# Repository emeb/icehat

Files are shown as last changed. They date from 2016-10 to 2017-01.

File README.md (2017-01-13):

# icehat

icehat is a small (Zero-sized) RPi hat which comprises a Lattice iCE40 Ultra
FPGA type ice5LP4K-SG48 along with voltage regulators, status LEDs and three
Digilent-style PMOD connectors.

This repository includes the full KiCAD board design source as well as C source
for an RPi user application which can configure the FPGA via GPIO and SPI ports
as well as communicate with a simple SPI slave hosted on the FPGA. Verilog
source for the FPGA test design is also included.

For more info on this project, please see the web page at:

http://ebrombaugh.studionebula.com/embedded/icehat/index.html

Credits: 

Portions of the KiCAD design are based on the RPi_Hat_Template from
xesscorp: https://github.com/xesscorp/RPi_Hat_Template

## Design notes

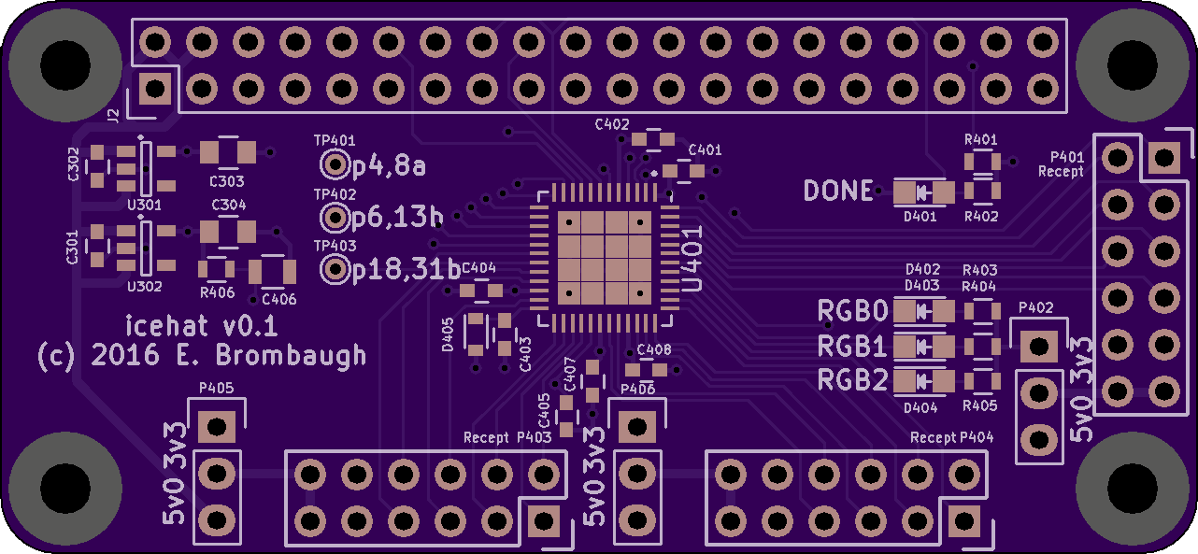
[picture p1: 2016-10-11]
docs/icehat_front.png

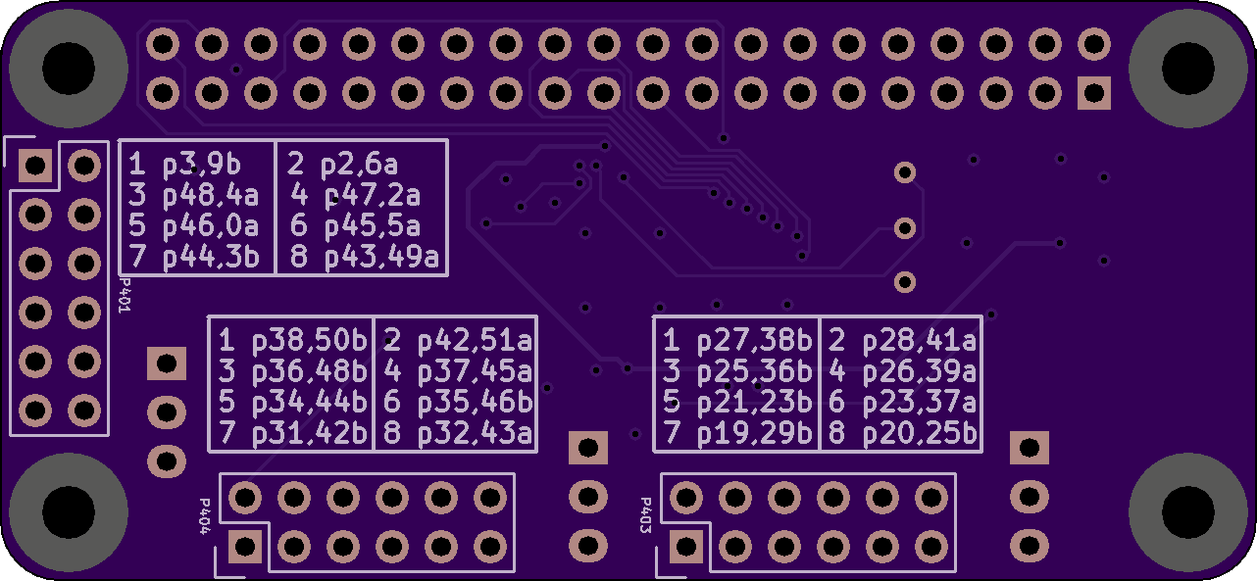
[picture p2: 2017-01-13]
docs/icehat_back.png

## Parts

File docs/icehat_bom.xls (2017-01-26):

Reference | Value | Footprint | M | Qty | Mfg P/N | Distributor | Distributor P/N | Notes
C401 | 0.1uf | Capacitors_SMD:C_0603 | 1
C402 | 0.1uf | Capacitors_SMD:C_0603 | 1
C403 | 0.1uf | Capacitors_SMD:C_0603 | 1
C404 | 0.1uf | Capacitors_SMD:C_0603 | 1
C405 | 0.1uf | Capacitors_SMD:C_0603 | 1
C407 | 0.1uf | Capacitors_SMD:C_0603 | 1
C408 | 0.1uf | Capacitors_SMD:C_0603 | 1 | 7 | C1608X7R1E104K080AA | Digi-Key | 445-1316-1-ND
C303 | 10uf | Capacitors_SMD:C_0805 | 1
C304 | 10uf | Capacitors_SMD:C_0805 | 1
C406 | 10uf | Capacitors_SMD:C_0805 | 1 | 3 | EMK212BB7106MG-T | Mouser | 963-EMK212BB7106MG-T
C301 | 1uf | Capacitors_SMD:C_0603 | 1
C302 | 1uf | Capacitors_SMD:C_0603 | 1 | 2 | GCM188R71E105KA64D | Mouser | 81-GCM188R71E105KA4D
D401 | LED | LEDs:LED_0805 | 1
D402 | LED | LEDs:LED_0805 | 1
D403 | LED | LEDs:LED_0805 | 1
D404 | LED | LEDs:LED_0805 | 1 | 4 | Generic 0805 LED
D405 | D | Diodes_SMD:D_0603 | 1 | 1 | CDSU4148 | Mouser | 750-CDSU4148
J2 | RPi_GPIO | emeb:Pin_Header_Straight_2x20 | 1 | 1 | M20-7832046 | Mouser | 855-M20-7832046
P402 | CONN_01X03 | Pin_Headers:Pin_Header_Straight_1x03 | 1
P405 | CONN_01X03 | Pin_Headers:Pin_Header_Straight_1x03 | 1
P406 | CONN_01X03 | Pin_Headers:Pin_Header_Straight_1x03 | 1 | 3 | Generic 0.1” pin headers
P401 | CONN_02X06 | Pin_Headers:Pin_Header_Straight_2x06 | 1
P403 | CONN_02X06 | Pin_Headers:Pin_Header_Straight_2x06 | 1
P404 | CONN_02X06 | Pin_Headers:Pin_Header_Straight_2x06 | 1 | 3 | PPPC062LJBN-RC | Digi-Key | S5559-ND
R401 | 10k | Resistors_SMD:R_0603 | 1
R406 | 100 | Resistors_SMD:R_0603 | 1 | 1 | ERJ-3GEYJ103V | Digi-Key | P10KGCT-ND
R402 | 2.2k | Resistors_SMD:R_0603 | 1 | 1 | ERJ-3GEYJ101V | Digi-Key | P100GCT-ND
R403 | 2.2k | Resistors_SMD:R_0603 | 1
R404 | 2.2k | Resistors_SMD:R_0603 | 1
R405 | 2.2k | Resistors_SMD:R_0603 | 1 | 4 | ERJ-3GEYJ222V | Digi-Key | P10KGCT-ND
U301 | MCP1802-3.3 | TO_SOT_Packages_SMD:SOT-23-5 | 1 | 1 | MCP1802T-3302I/OT | Digi-Key | MCP1802T-3302I/OTCT-ND
U302 | MCP1824-1.2 | TO_SOT_Packages_SMD:SOT-23-5 | 1 | 1 | MCP1824T-1202E/OT | Mouser | 579-MCP1824T-1202EOT
U401 | ice5lp4k_sg48 | emeb:QFN-48-1EP_7x7mm_Pitch0.5mm_DIY_PADS | 1 | 1 | ICE5LP4K-SG48ITR50 | Mouser | 842-CE5LP4KSG48ITR50

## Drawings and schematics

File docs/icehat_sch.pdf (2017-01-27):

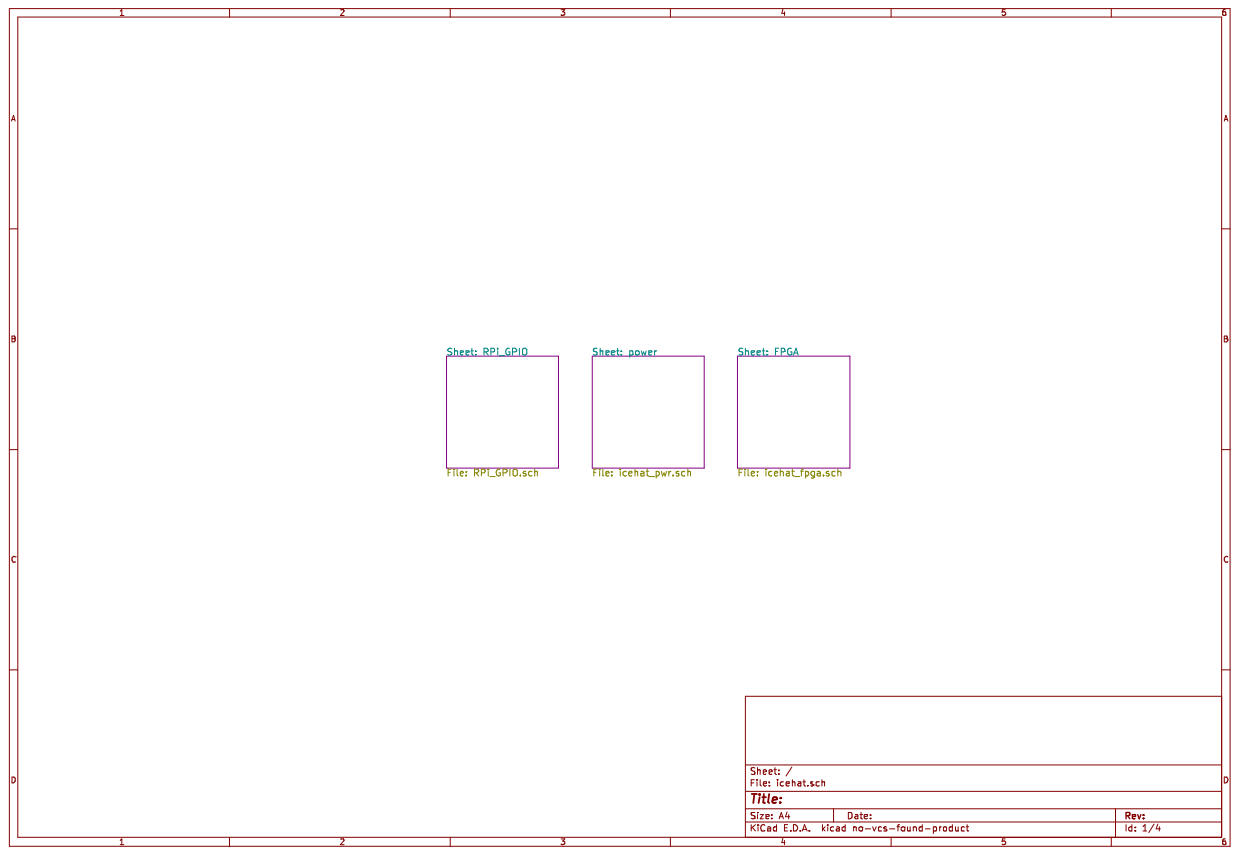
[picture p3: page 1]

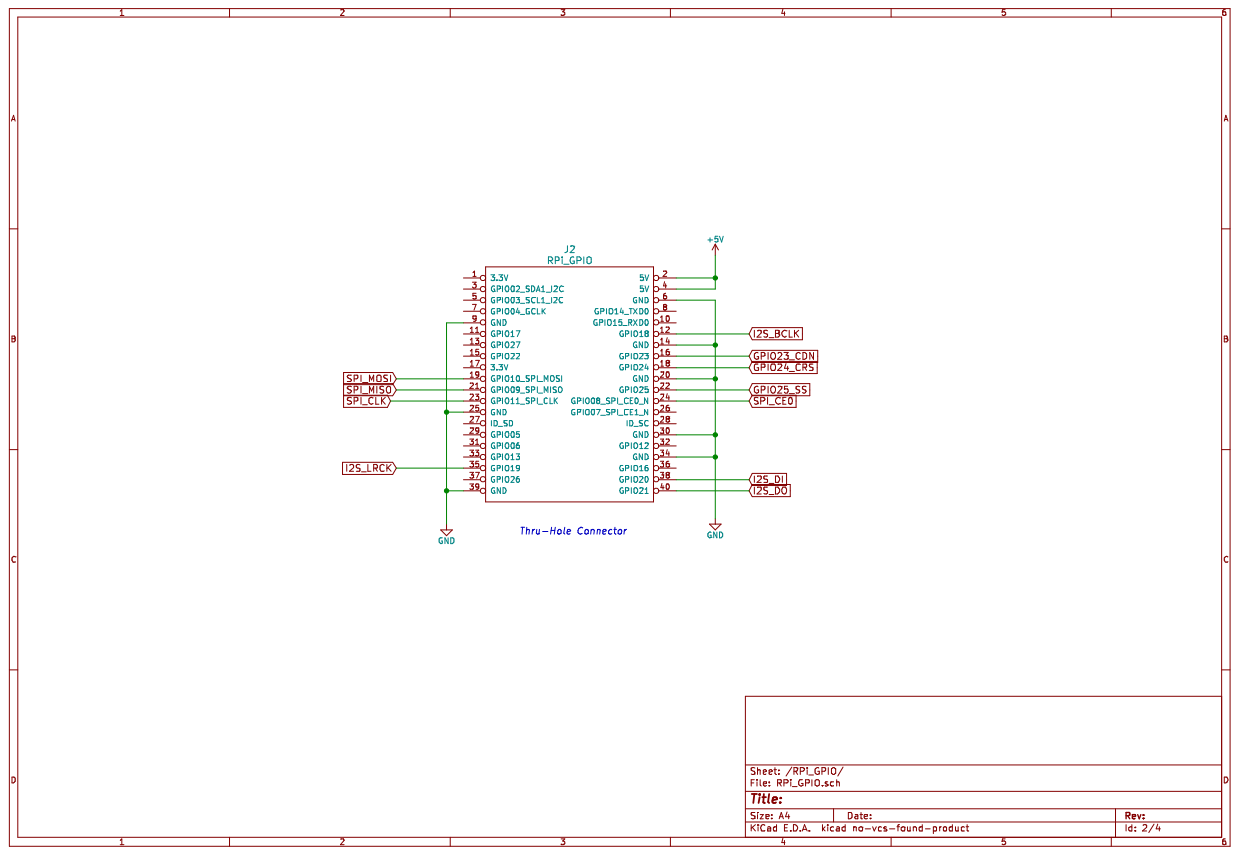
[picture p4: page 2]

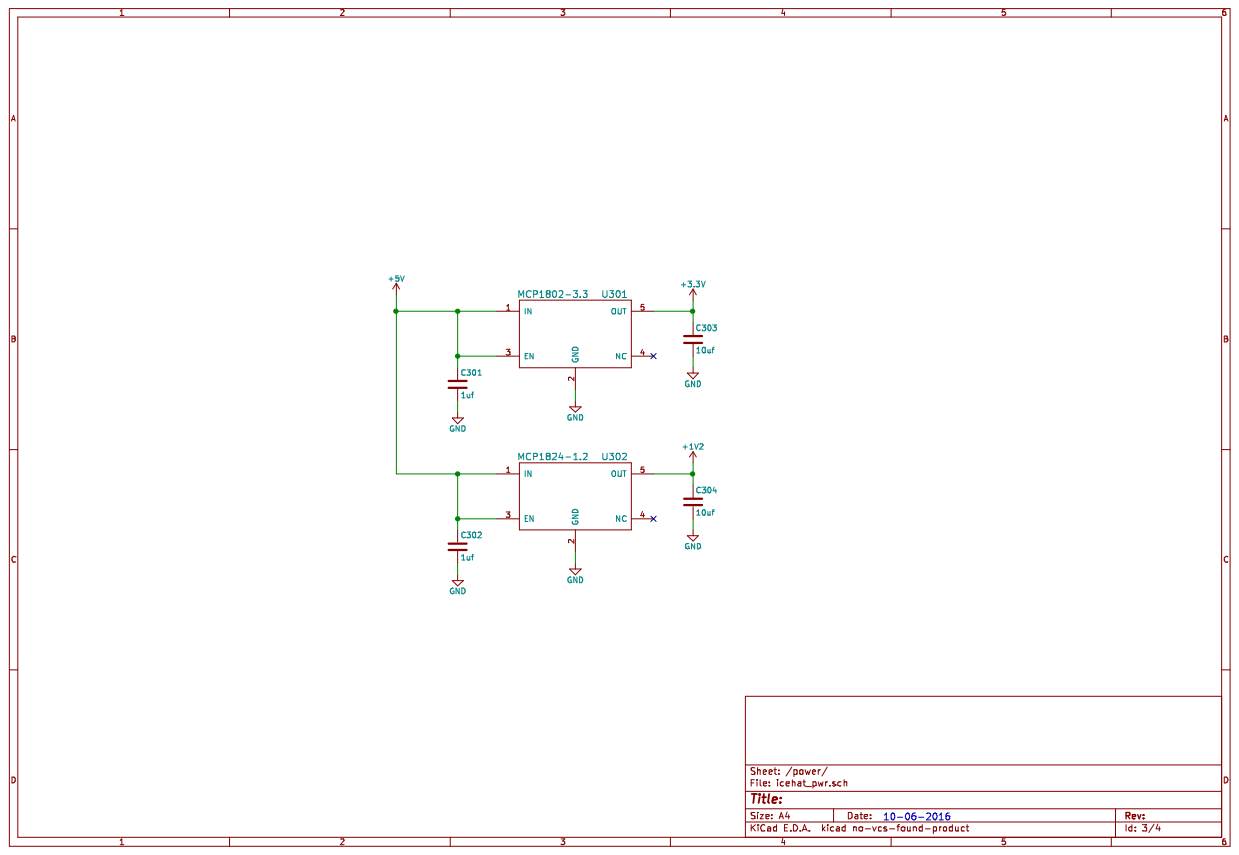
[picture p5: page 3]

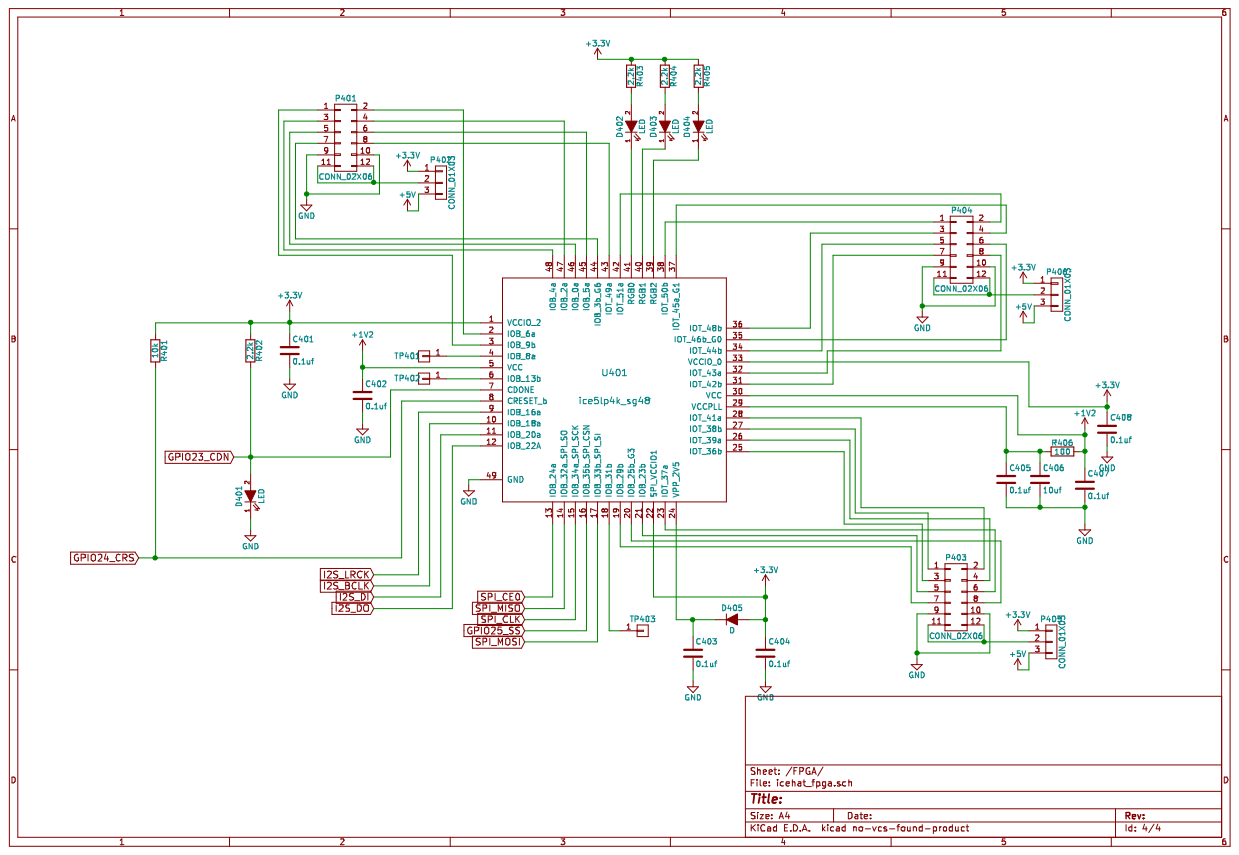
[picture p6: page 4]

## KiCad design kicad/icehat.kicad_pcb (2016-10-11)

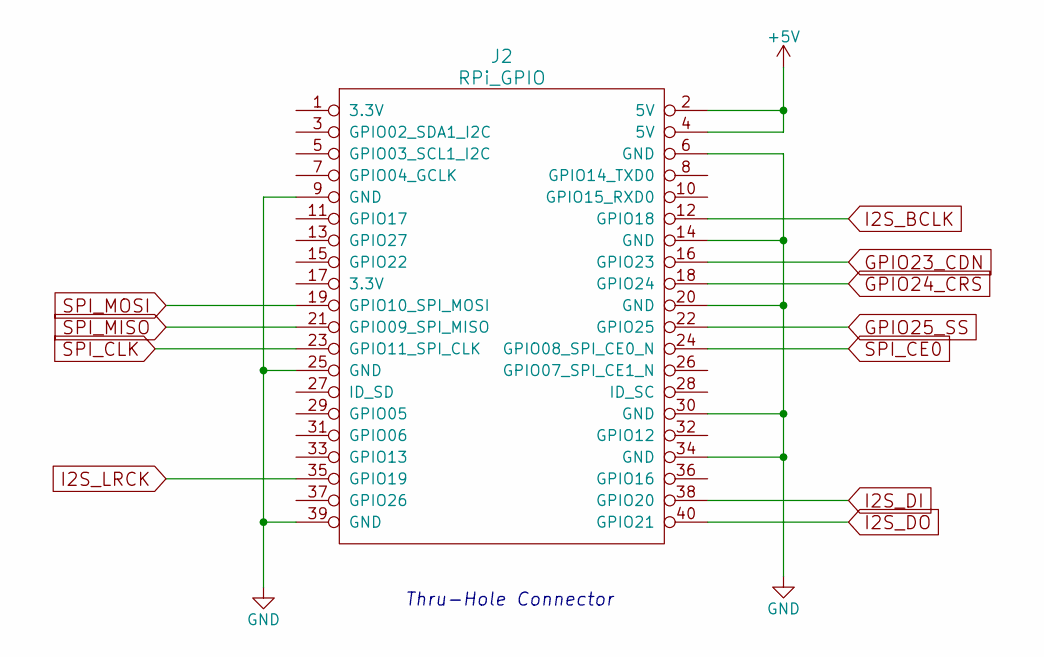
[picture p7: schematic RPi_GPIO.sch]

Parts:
J2: RPi_GPIO; Pin_Header_Straight_2x20

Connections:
+5V: J2.2 (5V), J2.4 (5V); also elsewhere on the board
GND: J2.6 (GND), J2.9 (GND), J2.14 (GND), J2.20 (GND), J2.25 (GND), J2.30 (GND), J2.34 (GND), J2.39 (GND); also elsewhere on the board
GPIO23_CDN: J2.16 (GPIO23); also elsewhere on the board
GPIO24_CRS: J2.18 (GPIO24); also elsewhere on the board
GPIO25_SS: J2.22 (GPIO25); also elsewhere on the board
I2S_BCLK: J2.12 (GPIO18); also elsewhere on the board
I2S_DI: J2.38 (GPIO20); also elsewhere on the board
I2S_DO: J2.40 (GPIO21); also elsewhere on the board
I2S_LRCK: J2.35 (GPIO19); also elsewhere on the board
SPI_CE0: J2.24 (GPIO08_SPI_CE0_N); also elsewhere on the board
SPI_CLK: J2.23 (GPIO11_SPI_CLK); also elsewhere on the board
SPI_MISO: J2.21 (GPIO09_SPI_MISO); also elsewhere on the board
SPI_MOSI: J2.19 (GPIO10_SPI_MOSI); also elsewhere on the board

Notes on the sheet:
Thru-Hole Connector

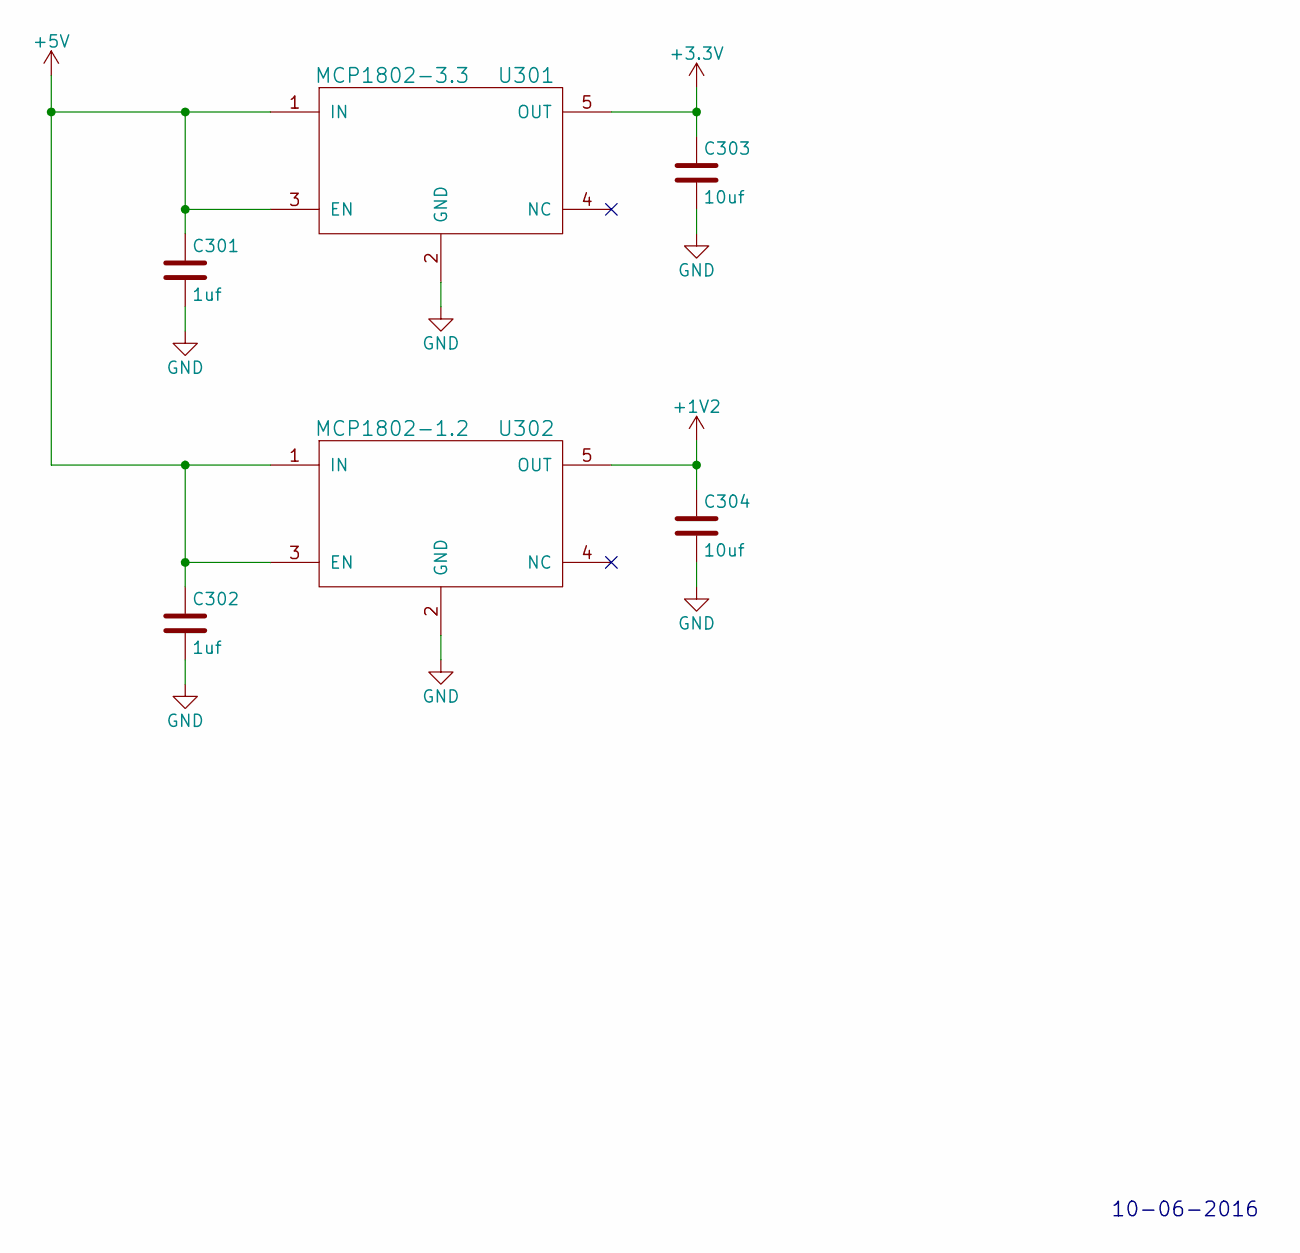
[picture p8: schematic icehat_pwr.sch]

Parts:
C301, C302: 1uf; C_0603
C303, C304: 10uf; C_0805
U301: MCP1802-3.3; SOT-23-5
U302: MCP1802-1.2; SOT-23-5

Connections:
+1V2: C304.1, U302.5 (OUT); also elsewhere on the board
+3V3: C303.1, U301.5 (OUT); also elsewhere on the board
+5V: C301.1, C302.1, U301.1 (IN), U301.3 (EN), U302.1 (IN), U302.3 (EN); also elsewhere on the board
GND: C301.2, C302.2, C303.2, C304.2, U301.2 (GND), U302.2 (GND); also elsewhere on the board

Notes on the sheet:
10-06-2016

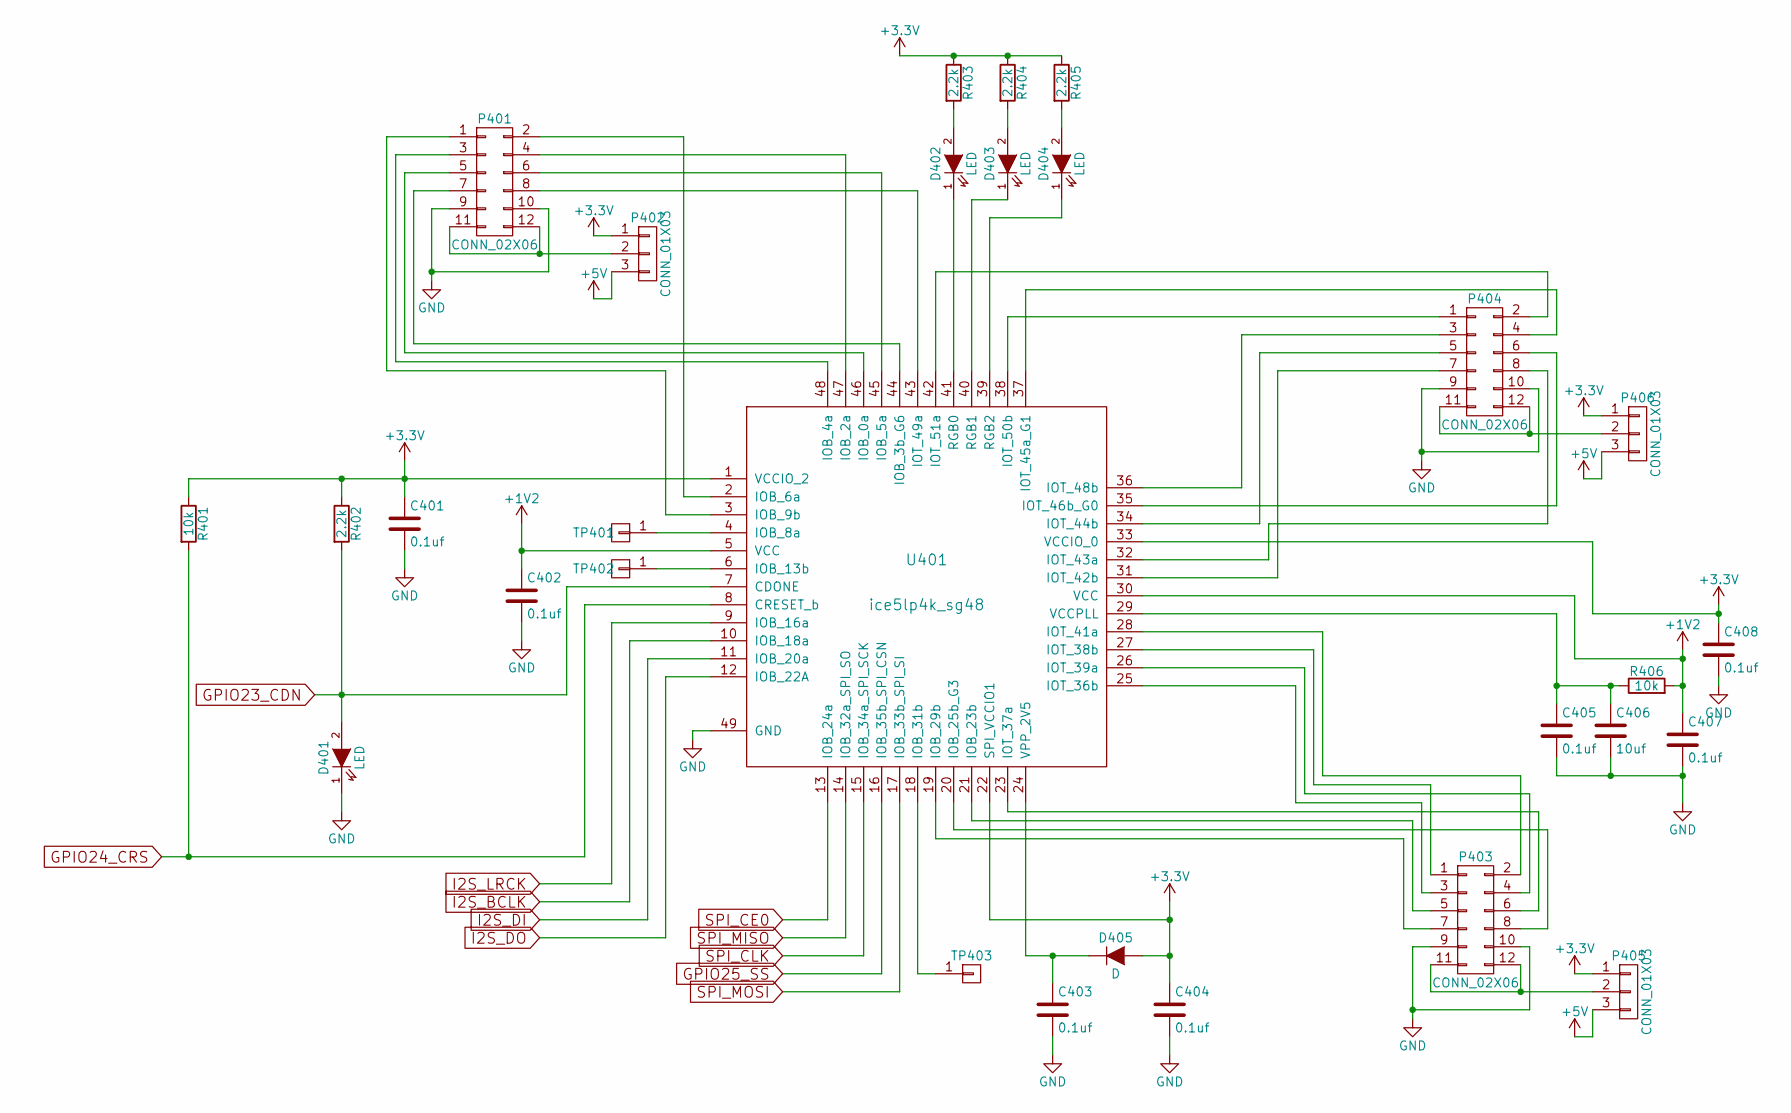
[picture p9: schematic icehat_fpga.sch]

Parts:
C401, C402, C403, C404, C405, C407, C408: 0.1uf; C_0603
C406: 10uf; R_0805
D401, D402, D403, D404: LED; LED_0805
D405: D; D_0603
P401, P403, P404: CONN_02X06; Pin_Header_Straight_2x06
P402, P405, P406: CONN_01X03; Pin_Header_Straight_1x03
R401, R406: 10k; R_0603
R402, R403, R404, R405: 2.2k; R_0603
TP401, TP402, TP403: CONN_01X01; PINTST
U401: ice5lp4k_sg48; QFN-48-1EP_7x7mm_Pitch0.5mm_DIY_PADS

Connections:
+1V2: C402.1, C407.1, R406.2, U401.5 (VCC), U401.30 (VCC); also elsewhere on the board
+3V3: C401.1, C404.1, C408.1, D405.2 (A), P402.1, P405.1, P406.1, R401.1, R402.1, R403.1, R404.1, R405.1, U401.1 (VCCIO_2), U401.22 (SPI_VCCIO1), U401.33 (VCCIO_0); also elsewhere on the board
+5V: P402.3, P405.3, P406.3; also elsewhere on the board
GND: C401.2, C402.2, C403.2, C404.2, C405.2, C406.2, C407.2, C408.2, D401.1 (K), P401.9, P401.10, P403.9, P403.10, P404.9, P404.10, U401.49 (GND); also elsewhere on the board
GPIO23_CDN: D401.2 (A), R402.2, U401.7 (CDONE); also elsewhere on the board
GPIO24_CRS: R401.2, U401.8 (CRESET_b); also elsewhere on the board
GPIO25_SS: U401.16 (IOB_35b_SPI_CSN); also elsewhere on the board
I2S_BCLK: U401.10 (IOB_18a); also elsewhere on the board
I2S_DI: U401.11 (IOB_20a); also elsewhere on the board
I2S_DO: U401.12 (IOB_22A); also elsewhere on the board
I2S_LRCK: U401.9 (IOB_16a); also elsewhere on the board
unnamed: C403.1, D405.1 (K), U401.24 (VPP_2V5)
unnamed: C405.1, C406.1, R406.1, U401.29 (VCCPLL)
unnamed: D402.1 (K), U401.41 (RGB0)
unnamed: D402.2 (A), R403.2
unnamed: D403.1 (K), U401.40 (RGB1)
unnamed: D403.2 (A), R404.2
unnamed: D404.1 (K), U401.39 (RGB2)
unnamed: D404.2 (A), R405.2
unnamed: P401.1, U401.3 (IOB_9b)
unnamed: P401.2, U401.2 (IOB_6a)
unnamed: P401.3, U401.48 (IOB_4a)
unnamed: P401.4, U401.47 (IOB_2a)
unnamed: P401.5, U401.46 (IOB_0a)
unnamed: P401.6, U401.45 (IOB_5a)
unnamed: P401.7, U401.44 (IOB_3b_G6)
unnamed: P401.8, U401.43 (IOT_49a)
unnamed: P401.11, P401.12, P402.2
unnamed: P403.1, U401.27 (IOT_38b)
unnamed: P403.2, U401.28 (IOT_41a)
unnamed: P403.3, U401.25 (IOT_36b)
unnamed: P403.4, U401.26 (IOT_39a)
unnamed: P403.5, U401.21 (IOB_23b)
unnamed: P403.6, U401.23 (IOT_37a)
unnamed: P403.7, U401.19 (IOB_29b)
unnamed: P403.8, U401.20 (IOB_25b_G3)
unnamed: P403.11, P403.12, P405.2
unnamed: P404.1, U401.38 (IOT_50b)
unnamed: P404.2, U401.42 (IOT_51a)
unnamed: P404.3, U401.36 (IOT_48b)
unnamed: P404.4, U401.37 (IOT_45a_G1)
unnamed: P404.5, U401.34 (IOT_44b)
unnamed: P404.6, U401.35 (IOT_46b_G0)
unnamed: P404.7, U401.31 (IOT_42b)
unnamed: P404.8, U401.32 (IOT_43a)
unnamed: P404.11, P404.12, P406.2
unnamed: TP401.1, U401.4 (IOB_8a)
unnamed: TP402.1, U401.6 (IOB_13b)
unnamed: TP403.1, U401.18 (IOB_31b)
SPI_CE0: U401.13 (IOB_24a); also elsewhere on the board
SPI_CLK: U401.15 (IOB_34a_SPI_SCK); also elsewhere on the board
SPI_MISO: U401.14 (IOB_32a_SPI_SO); also elsewhere on the board
SPI_MOSI: U401.17 (IOB_33b_SPI_SI); also elsewhere on the board

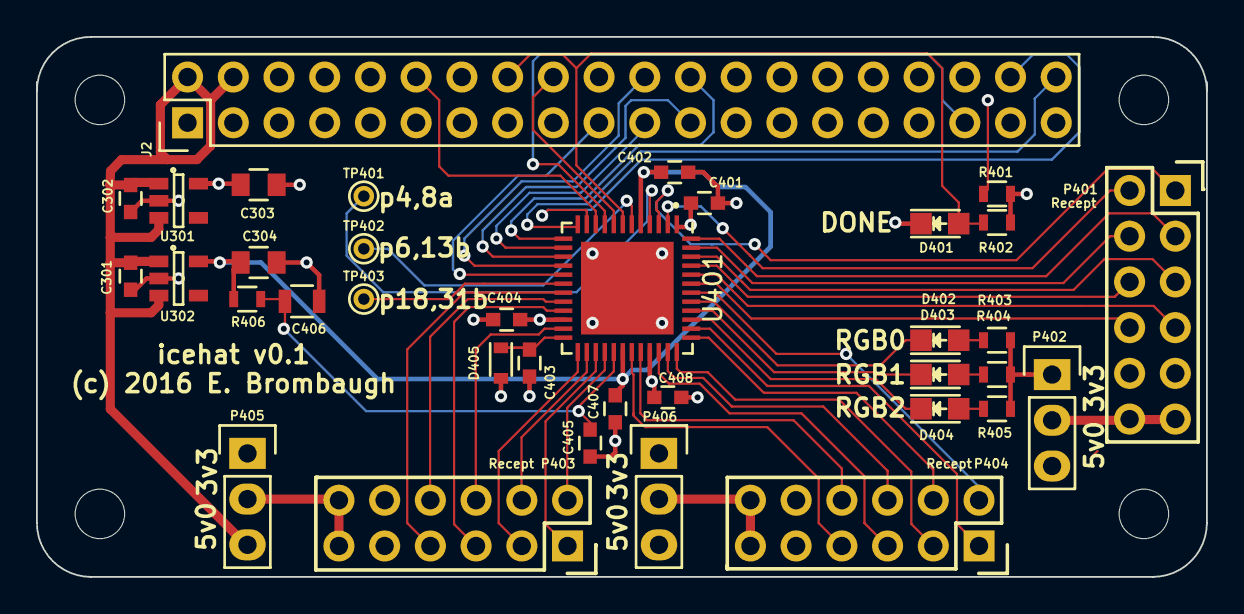
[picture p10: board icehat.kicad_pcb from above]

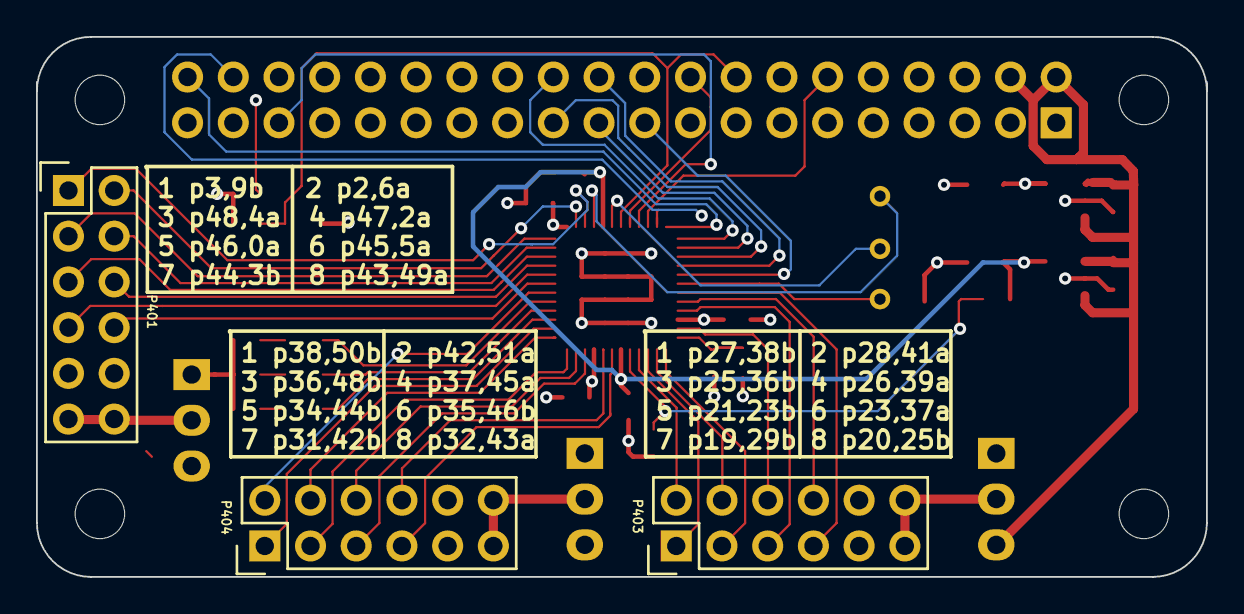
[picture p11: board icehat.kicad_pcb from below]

Board: 4 copper layers, 65.0 x 30.0 mm, 36 parts (3 on the bottom side), 53 nets.

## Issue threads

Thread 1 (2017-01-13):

How to program icehat?

liubenyuan, 2017-01-13:
Hi, Thanks for your project icehat.

I find that you do not have any jtag headers (sorry I just moved from Xilinx), how could I program icehat?

Or, can I add one FTDI pins to icehat?

emeb, 2017-01-13:
Lattice FPGAs do not require (or support) JTAG programming - they can
only be programmed via the SPI interface. On the Icehat the SPI
interface is connected to the Raspberry Pi SPI port so the FPGA can be
configured via programs running on the Raspberry Pi. In the github
repository I have provided source code for an application that can do
this, as well as a library of code that can be added to other applications.

Eric

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

liubenyuan, 2017-01-13:
Thanks ! Does ice40lp4k support LVDS input/output ? In
```
Using Differential I/O (LVDS, Sub-LVDS)
in iCE40 LP/HX Devices
```
It says that ice40lp4k has 20 lvds pairs, where are they ? I do not find any pins named as `_P` or `_N` as for Xilinx. I do not know whether this chip support long rang LVDS transmission.

emeb, 2017-01-13:
Lattice FPGAs do not require (or support) JTAG programming - they can only be programmed via the SPI interface. On the Icehat the SPI interface is connected to the Raspberry Pi SPI port so the FPGA can be configured via programs running on the Raspberry Pi. In the github repository I have provided source code for an application that can do this, as well as a library of code that can be added to other applications.

emeb, 2017-01-13:
Icehat does not use an LP/HX device - it is an Ultra device. Please see the data sheet for this family here:

http://www.latticesemi.com/view_document?document_id=51968

According to that document, LVDS is not specifically supported. It mentions that some pins provide differential input but then does not list which pins.

liubenyuan, 2017-01-13:
Thanks!

Closed 2017-01-13.

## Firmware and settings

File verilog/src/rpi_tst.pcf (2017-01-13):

# ##############################################################################

# iCEcube PCF

# Version:            2016.02.27810

# File Generated:     May 3 2016 09:34:27

# Family & Device:    iCE5LP4K

# Package:            SG48

# ##############################################################################

###IOSet List 17
set_io SPI_MISO 14
set_io SPI_SCLK 15
set_io SPI_CSL 13
set_io SPI_MOSI 17

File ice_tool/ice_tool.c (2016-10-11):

/* ice_tool.c - iCE40 configuration & control for raspberry pi               */
/* Copyright 2016 Eric Brombaugh                                             */
/*   This program is free software; you can redistribute it and/or modify
    it under the terms of the GNU General Public License as published by
    the Free Software Foundation; either version 2 of the License, or
    (at your option) any later version.

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
    You should have received a copy of the GNU General Public License
    along with this program; if not, write to the Free Software
    Foundation, Inc., 51 Franklin Street, Fifth Floor, Boston,
    MA 02110-1301 USA.
*/

#include <stdio.h>
#include <stdlib.h>
#include "ice_lib.h"

#define VERSION "0.1"
#define ARRAY_SIZE(a) (sizeof(a) / sizeof((a)[0]))

static void help(void) __attribute__ ((noreturn));

static void help(void)
{
	fprintf(stderr,
	    "Usage: ice_tool [-r addr][-w addr data][-v][-V] [BITSTREAM] \n"
		"  BITSTREAM is a file containing the FPGA bitstream to download\n"
		"  -r read SPI control port at addr\n"
		"  -w write SPI control port at addr w/ data\n"
		"  -v enables verbose progress messages\n"
		"  -V prints the tool version\n");
	exit(1);
}

int main(int argc, char **argv)
{
	iceblk *bs;
	int flags = 0, read = 0, write = 0, verbose = 0, cfg = 0;
	int addr = 0, data = 0;

	/* handle (optional) flags first */
	while (1+flags < argc && argv[1+flags][0] == '-')
	{
		switch (argv[1+flags][1])
		{
		case 'r':
			read = 1;
			if (2+flags < argc)
				addr = atoi(argv[flags+2]);
			flags++;
			break;
		case 'w':
			write = 1;
			if (2+flags < argc)
				addr = atoi(argv[flags+2]);
			if (3+flags < argc)
				data = atoi(argv[flags+3]);
			flags+=2;
			break;
		case 'v':
			verbose = 1;
			break;
		case 'V':
			fprintf(stderr, "ice_tool version %s\n", VERSION);
			exit(0);
		default:
			fprintf(stderr, "Error: Unsupported option "
				"\"%s\"!\n", argv[1+flags]);
			help();
			exit(1);
		}
		flags++;
	}
    
    /* configuring? */
	if(argc > flags + 1)
        cfg = 1;

	/* open up hardware */
	if((bs = ice_init(cfg, verbose)) == NULL)
	{
		fprintf(stderr, "Couldn't access hardware\n");
		exit(2);
	}
	
	/* send bitstream to FPGA or SPI Flash if bitfile name available*/
	if(cfg)
	{
        /* Configure FPGA */
        if(verbose == 1) fprintf(stderr, "Configuring FPGA...\n");

        if(ice_cfg(bs, argv[flags + 1]))
        {
            fprintf(stderr, "Error sending bitstream to FPGA\n");
        }
	}

	/* spi read/write? */
	if(read || write)
	{
		int ret;
		uint8_t tx[] = {0x00, 0x00, 0x00, 0x00, 0x00};
		uint8_t rx[ARRAY_SIZE(tx)] = {0, };
		
		/* Build message */
		tx[0] = addr & 0x7f;	// set address
		if(read)
		{
			fprintf(stderr, "Read 0x%02X\n", addr);
			tx[0] |= 0x80;
		}

		if(write)
		{
			fprintf(stderr, "Write 0x%02X 0x%08X\n", addr, data);
			tx[1] = (data >> 24) & 0xff;
			tx[2] = (data >> 16) & 0xff;
			tx[3] = (data >>  8) & 0xff;
			tx[4] = (data >>  0) & 0xff;
		}
 
		/* send a message */
		ret = ice_spi_txrx(bs, tx, rx, ARRAY_SIZE(tx));
		if (ret == 1)
		{
			fprintf(stderr, "Can't send spi message\n");
		}
		else
		{
			/* Dump RX Message */
			fprintf(stderr, "Sent: ");
			for (ret = 0; ret < ARRAY_SIZE(tx); ret++)
			{
				fprintf(stderr, "%.2X ", tx[ret]);
			}
			fprintf(stderr, "\n");
			fprintf(stderr, "Received: ");
			for (ret = 0; ret < ARRAY_SIZE(rx); ret++)
			{
				fprintf(stderr, "%.2X ", rx[ret]);
			}
			fprintf(stderr, "\n");
		}
	}
	
	/* All done */
	ice_delete(bs);
	
	return 0;
}

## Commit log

2016-10-11 Initial commit of icehat RPi FPGA hat.
    [RPi_GPIO.sch, icehat.kicad_pcb, icehat.sch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]
2016-10-11 Added board render and schematic
2017-01-26 Added BOM
    [icehat_bom.xls]
2017-01-27 Fix some component values
    [icehat_fpga.sch, icehat_pwr.sch]

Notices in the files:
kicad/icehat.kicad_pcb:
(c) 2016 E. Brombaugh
